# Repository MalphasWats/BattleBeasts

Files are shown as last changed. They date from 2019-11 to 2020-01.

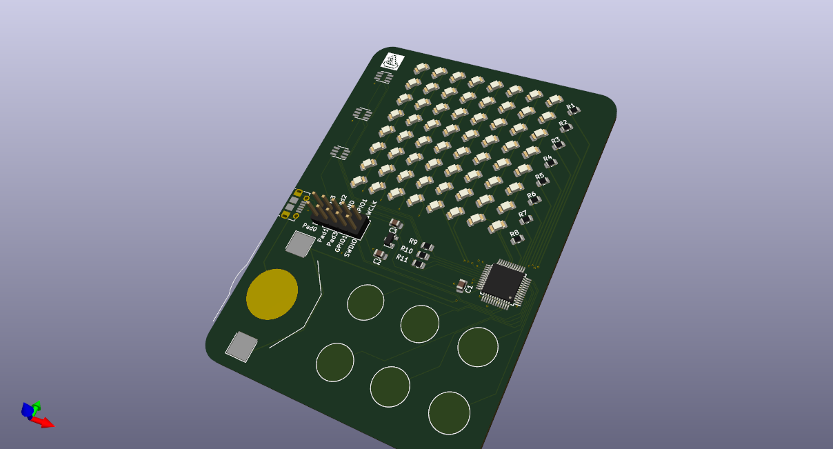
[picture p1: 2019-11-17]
assets/PCB-3D.png

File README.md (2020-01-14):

# BattleBeasts

PCBWAY

Just before Christmas, I had a kind offer from the folks at [PCBWay][PCBWAY] to work on a small maker project. I saw this as a great opportunity to experiment with some new tech and designed a new board around the Microchip SAMD21G microcontroller.

I've always wanted to build a 'Tamagotchi'-type device, so I designed a simple development board the size of a standard playing card with an 8x8 LED matrix and some capacitative-touch buttons. I knocked my design up in KiCAD in a couple of hours:

KiCAD PCB Layout

and uploaded the files to the PCB website.

Not long afterwards I got these beauties in the post:

PCBWay PCBs

I'd also asked for a solder paste stencil. I was a little bit lazy and just added a comment for it to be made the same size as the board and the guys at PCBWay did it for me which was really great. The boards were really good quality - I poked at them with my multimeter to check continuity and everything was fine.

The black soldermask looks so good on bare PCBs.

Using some old PCBs from another project, I taped the stencil down to my workbench:

Stencil taped to PCB

and applied the paste. I think my paste might be a little bit old but it still looks good. I'd really like to get a little USB microscope so I can take proper solder paste glamour shots!

Solder paste porn

I then very patiently placed most of the components - I don't have any RGB LEDs or coin cell holders so I left those off. This is easily the highest component count I've assembled so far and it went really well. I was paranoid about the LEDs being the right way around so I check every single one out of the reel-strip!

After blasting it with my hot air gun, I think it looks pretty good:

Finished Board.

I can power the board via the USB connector whilst I'm developing and I can add the RGBs to it later once I've got the matrix working.

My main goal with this board is to build up my Arm MCU development toolchain so getting some code up and running is the next step!

[PCBWAY]: http://www.pcbway.com
[PCBWAYLOGO]: http://www.subdimension.co.uk/files/2020-01-10-New-Year-New-Gear/pcbway.png
[KiCAD]: http://www.subdimension.co.uk/files/2020-01-10-New-Year-New-Gear/KiCAD.png
[BOARDS]: http://www.subdimension.co.uk/files/2020-01-10-New-Year-New-Gear/boards.jpeg
[STENCIL]: http://www.subdimension.co.uk/files/2020-01-10-New-Year-New-Gear/stencil.jpeg
[PASTE]: http://www.subdimension.co.uk/files/2020-01-10-New-Year-New-Gear/paste.jpeg
[FINISHED]: http://www.subdimension.co.uk/files/2020-01-10-New-Year-New-Gear/finished.jpeg
[BB]: https://github.com/MalphasWats/BattleBeasts

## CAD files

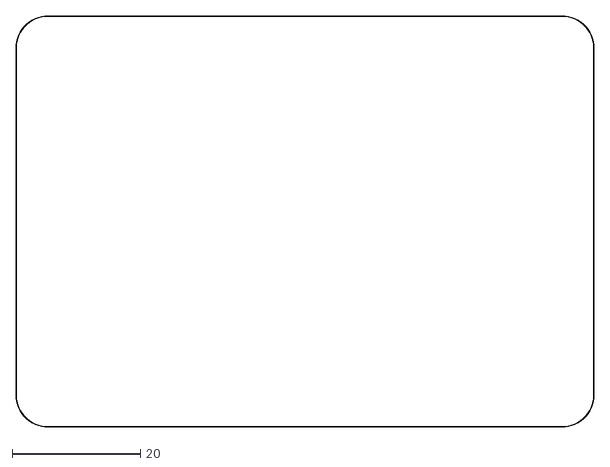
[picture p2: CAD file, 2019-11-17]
outline.dxf
90.0 x 64.0

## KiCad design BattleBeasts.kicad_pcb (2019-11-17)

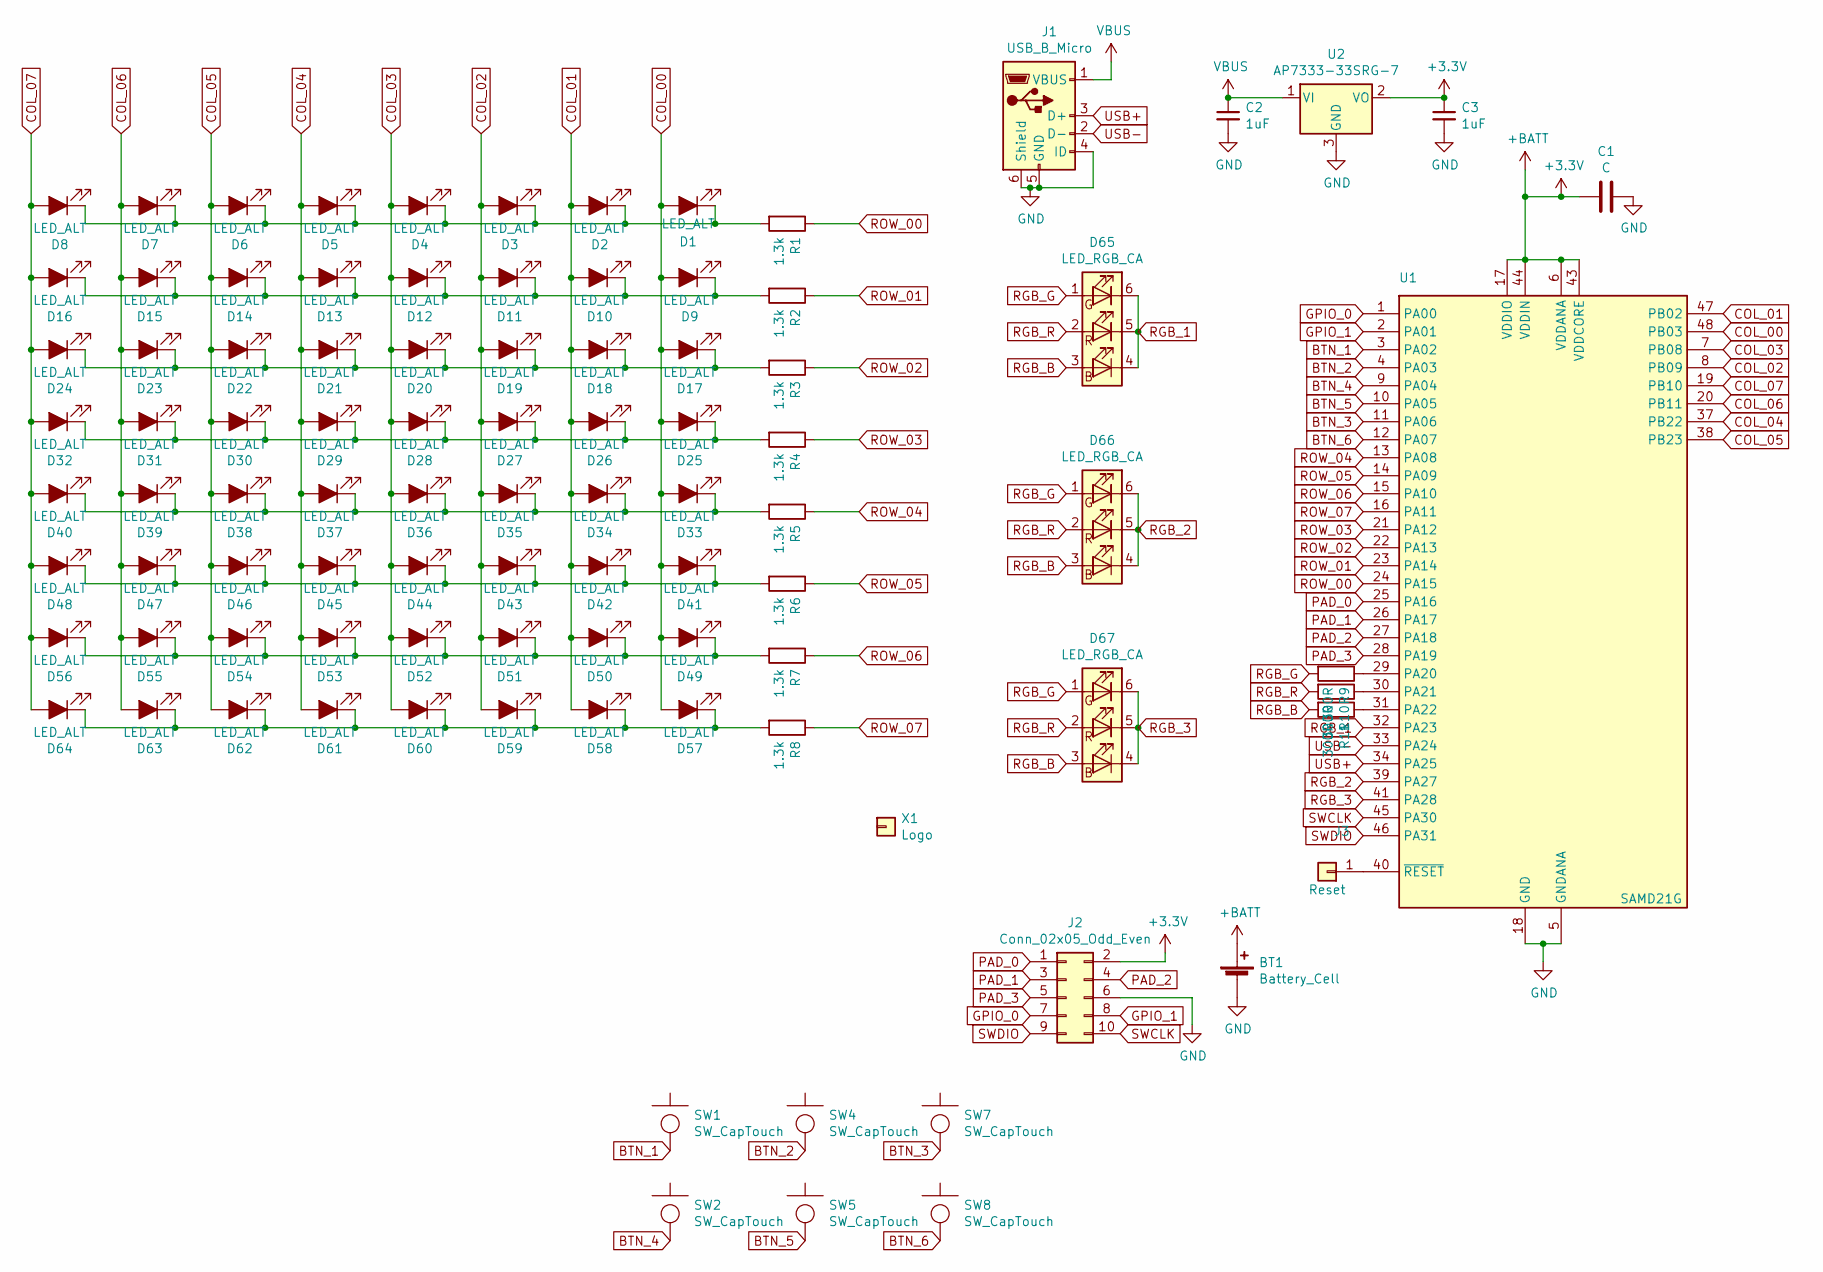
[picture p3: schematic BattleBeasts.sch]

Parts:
BT1: Battery_Cell; BatteryHolder_Keystone_3002_1x2032
C1: C; C_0805_2012Metric
C2, C3: 1uF; C_0805_2012Metric_Pad1.15x1.40mm_HandSolder
D1, D2, D3, D4, D5, D6, D7, D8, D9, D10, D11, D12, D13, D14, D15, D16, D17, D18, D19, D20, D21, D22, D23, D24, D25, D26, D27, D28, D29, D30, D31, D32, D33, D34, D35, D36, D37, D38, D39, D40, D41, D42, D43, D44, D45, D46, D47, D48, D49, D50, D51, D52, D53, D54, D55, D56, D57, D58, D59, D60, D61, D62, D63, D64: LED_ALT; LED_1206_3216Metric_Clean
D65, D66, D67: LED_RGB_CA; LED_Avago_PLCC6_3x2.8mm
J1: USB_B_Micro; USB_Micro-B_Molex-105017-0001
J2: Conn_02x05_Odd_Even; PinHeader_2x05_P2.54mm_Vertical
J3: Reset; TestPoint_Pad_1.0x1.0mm
R1, R2, R3, R4, R5, R6, R7, R8: 1.3k; R_0805_2012Metric
R9, R10, R11: 300R; R_0805_2012Metric
SW1, SW2, SW4, SW5, SW7, SW8: SW_CapTouch; CapTouch_D8.0mm
U1: SAMD21G; TQFP-48_7x7mm_P0.5mm
U2: AP7333-33SRG-7; SOT-23
X1: Logo; LOGO_5x5

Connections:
+3V3: BT1.1 (+), C1.2, C3.1, J2.2, U1.6 (VDDANA), U1.17 (VDDIO), U1.36 (VDDIO), U1.43 (VDDCORE), U1.44 (VDDIN), U2.2 (VO)
BTN_1: SW1.1, U1.3 (PA02)
BTN_2: SW4.1, U1.4 (PA03)
BTN_3: SW7.1, U1.11 (PA06)
BTN_4: SW2.1, U1.9 (PA04)
BTN_5: SW5.1, U1.10 (PA05)
BTN_6: SW8.1, U1.12 (PA07)
COL_00: D1.2 (A), D9.2 (A), D17.2 (A), D25.2 (A), D33.2 (A), D41.2 (A), D49.2 (A), D57.2 (A), U1.48 (PB03)
COL_01: D2.2 (A), D10.2 (A), D18.2 (A), D26.2 (A), D34.2 (A), D42.2 (A), D50.2 (A), D58.2 (A), U1.47 (PB02)
COL_02: D3.2 (A), D11.2 (A), D19.2 (A), D27.2 (A), D35.2 (A), D43.2 (A), D51.2 (A), D59.2 (A), U1.8 (PB09)
COL_03: D4.2 (A), D12.2 (A), D20.2 (A), D28.2 (A), D36.2 (A), D44.2 (A), D52.2 (A), D60.2 (A), U1.7 (PB08)
COL_04: D5.2 (A), D13.2 (A), D21.2 (A), D29.2 (A), D37.2 (A), D45.2 (A), D53.2 (A), D61.2 (A), U1.37 (PB22)
COL_05: D6.2 (A), D14.2 (A), D22.2 (A), D30.2 (A), D38.2 (A), D46.2 (A), D54.2 (A), D62.2 (A), U1.38 (PB23)
COL_06: D7.2 (A), D15.2 (A), D23.2 (A), D31.2 (A), D39.2 (A), D47.2 (A), D55.2 (A), D63.2 (A), U1.20 (PB11)
COL_07: D8.2 (A), D16.2 (A), D24.2 (A), D32.2 (A), D40.2 (A), D48.2 (A), D56.2 (A), D64.2 (A), U1.19 (PB10)
GND: BT1.2 (-), C1.1, C2.2, C3.2, J1.4 (ID), J1.5 (GND), J1.6 (Shield), J2.6, U1.5 (GNDANA), U1.18 (GND), U1.35 (GND), U1.42 (GND), U2.3 (GND)
GPIO_0: J2.7, U1.1 (PA00)
GPIO_1: J2.8, U1.2 (PA01)
unnamed: D1.1 (K), D2.1 (K), D3.1 (K), D4.1 (K), D5.1 (K), D6.1 (K), D7.1 (K), D8.1 (K), R1.2
unnamed: D9.1 (K), D10.1 (K), D11.1 (K), D12.1 (K), D13.1 (K), D14.1 (K), D15.1 (K), D16.1 (K), R2.2
unnamed: D17.1 (K), D18.1 (K), D19.1 (K), D20.1 (K), D21.1 (K), D22.1 (K), D23.1 (K), D24.1 (K), R3.2
unnamed: D25.1 (K), D26.1 (K), D27.1 (K), D28.1 (K), D29.1 (K), D30.1 (K), D31.1 (K), D32.1 (K), R4.2
unnamed: D33.1 (K), D34.1 (K), D35.1 (K), D36.1 (K), D37.1 (K), D38.1 (K), D39.1 (K), D40.1 (K), R5.2
unnamed: D41.1 (K), D42.1 (K), D43.1 (K), D44.1 (K), D45.1 (K), D46.1 (K), D47.1 (K), D48.1 (K), R6.2
unnamed: D49.1 (K), D50.1 (K), D51.1 (K), D52.1 (K), D53.1 (K), D54.1 (K), D55.1 (K), D56.1 (K), R7.2
unnamed: D57.1 (K), D58.1 (K), D59.1 (K), D60.1 (K), D61.1 (K), D62.1 (K), D63.1 (K), D64.1 (K), R8.2
unnamed: J3.1, U1.40 (~RESET)
unnamed: R9.1, U1.29 (PA20)
unnamed: R10.1, U1.30 (PA21)
unnamed: R11.1, U1.31 (PA22)
PAD_0: J2.1, U1.25 (PA16)
PAD_1: J2.3, U1.26 (PA17)
PAD_2: J2.4, U1.27 (PA18)
PAD_3: J2.5, U1.28 (PA19)
RGB_1: D65.4 (BA), D65.5 (GA), D65.6 (RA), U1.32 (PA23)
RGB_2: D66.4 (BA), D66.5 (GA), D66.6 (RA), U1.39 (PA27)
RGB_3: D67.4 (BA), D67.5 (GA), D67.6 (RA), U1.41 (PA28)
RGB_B: D65.3 (BK), D66.3 (BK), D67.3 (BK), R11.2
RGB_G: D65.1 (RK), D66.1 (RK), D67.1 (RK), R9.2
RGB_R: D65.2 (GK), D66.2 (GK), D67.2 (GK), R10.2
ROW_00: R1.1, U1.24 (PA15)
ROW_01: R2.1, U1.23 (PA14)
ROW_02: R3.1, U1.22 (PA13)
ROW_03: R4.1, U1.21 (PA12)
ROW_04: R5.1, U1.13 (PA08)
ROW_05: R6.1, U1.14 (PA09)
ROW_06: R7.1, U1.15 (PA10)
ROW_07: R8.1, U1.16 (PA11)
SWCLK: J2.10, U1.45 (PA30)
SWDIO: J2.9, U1.46 (PA31)
USB+: J1.3 (D+), U1.34 (PA25)
USB-: J1.2 (D-), U1.33 (PA24)
VBUS: C2.1, J1.1 (VBUS), U2.1 (VI)

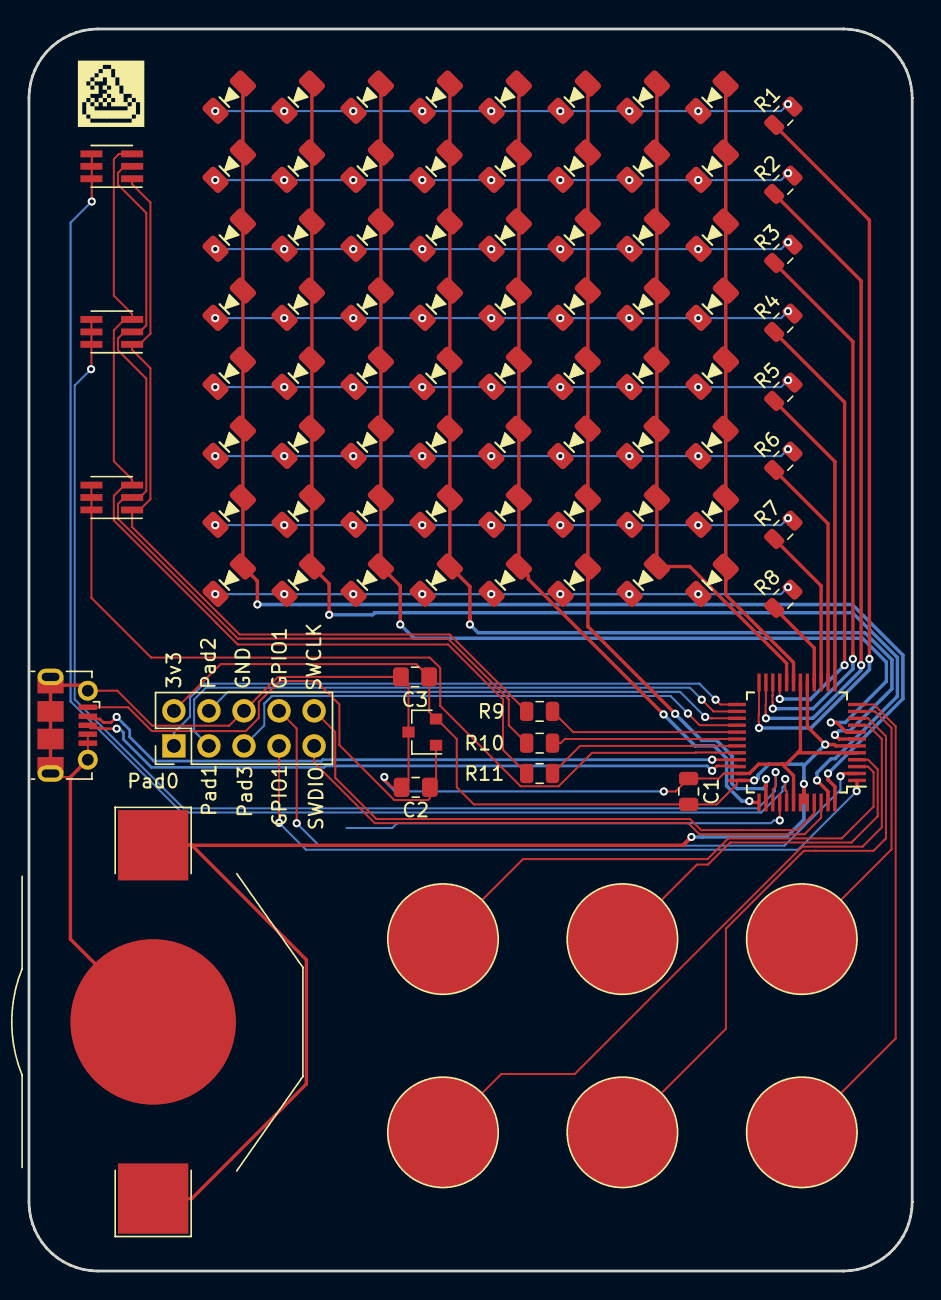
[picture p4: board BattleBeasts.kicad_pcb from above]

Board: 2 copper layers, 64.0 x 90.0 mm, 94 parts (1 on the bottom side), 53 nets.

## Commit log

2019-11-17 BattleBeasts custom pcb idea
    [BattleBeasts.kicad_pcb, BattleBeasts.sch, outline.dxf]
2020-01-12 using the wrong device!
